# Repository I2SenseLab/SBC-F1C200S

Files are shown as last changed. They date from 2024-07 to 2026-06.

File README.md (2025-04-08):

Remember to Initialize Submodules

```
git submodule update --init
```

To Grab the device defconfig

```
BR2_EXTERNAL=../simple_sbc make f1c200s_simple_sbc_defconfig
```

To make modifications to the config run

```
make menuconfig or xconfig (recommended)
```

To make the actual bin file run

```
make clean
make
```

To make on WSL with a slightly wonky path try

```
PATH=$(grep -v '[[:space:]]'<<<"${PATH//:/$'\n'}"|paste -sd:) make
```

```
To save changes to the defconfig
```

make savedefconfig

```

## JLCPCB Fabrication Note 

The usb differential traces have been routed according to this using their online calculator. Other processes will need these trace widths to be adjusted.

| Impedance (Ω) | Type                     | Signal Layer | Top Ref | Bottom Ref | Trace Width (mm) | Trace Spacing (mm) | Impedance Trace to Copper (mm) |
|--------------|-------------------------|--------------|---------|------------|------------------|------------------|----------------------------|
| 90           | Coplanar Differential Pair | L1           | /       | L2         | 0.1974           | 0.1300           | 0.1900                     |
| 90           | Coplanar Differential Pair | L2           | L1      | L3         | 0.1511           | 0.1300           | 0.1900                     |
| 90           | Coplanar Differential Pair | L3           | L2      | L4         | 0.1511           | 0.1300           | 0.1900                     |
| 90           | Coplanar Differential Pair | L4           | L3      | /          | 0.1974           | 0.1300           | 0.1900                     |

## To write img file into sd card we use in linux

```

sudo dd if=sdcard.img of=/dev/* bs=1M status=progress
sync

```

Note 'of=/dev/*' make sure you choose the correct dev device for the appropriate sd card

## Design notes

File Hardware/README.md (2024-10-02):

# Design Notes - Erata 

Initial Board Ordered 9th July 2024 - $148.59
This was for 5 boards assembled. There were a few minor issues with the initial board which have been both corrected and improved upon.

- The board moves the SD Card to the correct interface. This should allow full size SD cards to be run. I would assume a 32GB limit however.
- 16MB of Nand flash has been added to the design to act as the boot rom 
- A RP2040 and associated circuitry has been added to facilitate easy communication through the F1C200S UART interface without requiring USB Gadget to be fully functional initially.

# Note
- Manually Verified and Adjusted the uploaded Bill of Materials.
- At time of writing October 2nd, waiting on JLCPCB parts order to be fully fulfilled before placing PCB order.

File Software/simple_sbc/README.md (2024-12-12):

## Usage
The board has an unpopulated header for the SPI0 port which can be used to write to the flash chip directly. The F1C100 chip also includes a USB stack and SPI Flash driver in the internal bootloader in "FEL" mode, which can be used to write to the first 16MB of the chip.
* To force the device in to FEL mode, first bridge the CS pin with 3v3 to pull the line high and make the F1c100 footloader think there is no boot device.
* Plug the board in to a PC via USB. The LCD should light up white, and the device should enumerate as a USB device.
* Remove the bridge from chip select (CS) pin.
* Follow the instructions to get **sunxi-tools** for your OS [here](https://linux-sunxi.org/FEL).
* Build the Buildroot external tree:
```
BR2_EXTERNAL=../simple_sbc make f1c200s_simple_sbc_defconfig
```
* Use **sunxi-fel** to write the *flash.bin* file to the flash drive:
```
./sunxi-fel -p spiflash-write 0 flash.bin
```
* Reboot the device by either bridging the *reset* jumper, or clycling power.

## Benchmark Results 

# dhrystone

Dhrystone Benchmark, Version 2.1 (Language: C)

Program compiled without 'register' attribute

Please give the number of runs through the benchmark: 1000000000

Execution starts, 1000000000 runs through Dhrystone
Execution ends

Final values of the variables used in the benchmark:

Int_Glob:            5
        should be:   5
Bool_Glob:           1
        should be:   1
Ch_1_Glob:           A
        should be:   A
Ch_2_Glob:           B
        should be:   B
Arr_1_Glob[8]:       7
        should be:   7
Arr_2_Glob[8][7]:    1000000010
        should be:   Number_Of_Runs + 10
Ptr_Glob->
  Ptr_Comp:          94608
        should be:   (implementation-dependent)
  Discr:             0
        should be:   0
  Enum_Comp:         2
        should be:   2
  Int_Comp:          17
        should be:   17
  Str_Comp:          DHRYSTONE PROGRAM, SOME STRING
        should be:   DHRYSTONE PROGRAM, SOME STRING
Next_Ptr_Glob->
  Ptr_Comp:          94608
        should be:   (implementation-dependent), same as above
  Discr:             0
        should be:   0
  Enum_Comp:         1
        should be:   1
  Int_Comp:          18
        should be:   18
  Str_Comp:          DHRYSTONE PROGRAM, SOME STRING
        should be:   DHRYSTONE PROGRAM, SOME STRING
Int_1_Loc:           5
        should be:   5
Int_2_Loc:           13
        should be:   13
Int_3_Loc:           7
        should be:   7
Enum_Loc:            1
        should be:   1
Str_1_Loc:           DHRYSTONE PROGRAM, 1'ST STRING
        should be:   DHRYSTONE PROGRAM, 1'ST STRING
Str_2_Loc:           DHRYSTONE PROGRAM, 2'ND STRING
        should be:   DHRYSTONE PROGRAM, 2'ND STRING

Microseconds for one run through Dhrystone:    1.8
Dhrystones per Second:                      565163.3

## Acknowledgments
This project is based heavily on the work of others; I would like to acknowledge these project in particular:
* https://github.com/thirtythreeforty/businesscard-linux/tree/master
* https://github.com/florpor/licheepi-nano/tree/master
* [F1C100 Datasheet](https://whycan.com/files/members/3/F1C100s_Datasheet_V1_0.pdf)
* [Lichee-Pi Nano](https://wiki.sipeed.com/hardware/en/lichee/Nano/Nano.html)

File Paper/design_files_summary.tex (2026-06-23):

\begin{tabu} to \linewidth {|X|X|X[1.5,1]|X[1.5,1]|}
\hline
\textbf{Design filename} & \textbf{File type} & \textbf{Open source license} & \textbf{Location of the file} \\hline

SimpleSBC.dip & DipTrace schematic and PCB design files & Apache-2.0 & Repository associated with this article \\hline

SimpleSBC_gerber.zip & Manufacturing files (Gerber, drill, fabrication outputs) & Apache-2.0 & Repository associated with this article \\hline

sbcBOM.csv & Bill of materials & Apache-2.0 & Repository associated with this article \\hline

sbcPNP.csv & Pick-and-place assembly file & Apache-2.0 & Repository associated with this article \\hline

SimpleSBC_EnclosureTop.stl, SimpleSBC_EnclosureBottom.stl & Mechanical enclosure CAD files & Apache-2.0 & Repository associated with this article \\hline

f1c200s_simple_sbc.dts, f1c200s_simple_sbc.dtsi & Linux device tree source files & Apache-2.0 & Repository associated with this article \\hline

f1c200s_simple_sbc_defconfig & Buildroot configuration files & Apache-2.0 & Repository associated with this article \\hline

pico-uart-bridge & RP2040 USB-to-UART firmware source code & Apache-2.0 & Repository associated with this article \\hline

0001-st7789v-support-dc-gpio-8bit-spi.patch & Linux kernel patch enabling LCD support & Apache-2.0 & Repository associated with this article \\hline

\end{tabu}

\vskip 0.3cm

\textbf{SimpleSBC.dip} \
DipTrace project containing the complete schematic and PCB layout of the single-board computer. This file may be modified to adapt the design to alternative research applications or form factors.

\textbf{SimpleSBC_gerber.zip} \
Manufacturing-ready fabrication files used for PCB production. These files can be directly submitted to PCB fabrication services.

\textbf{sbcBOM.csv} \
Bill of materials listing all components required to assemble the hardware platform, including manufacturer part numbers and quantities.

\textbf{sbcPNP.csv} \
Pick-and-place file used for automated assembly of the PCB. This file enables low-cost assembly through commercial PCB assembly services.

\textbf{SimpleSBC_EnclosureTop.stl, SimpleSBC_EnclosureBottom.stl} \
3D-printable enclosure files providing mechanical protection for the assembled board while maintaining access to connectors and interfaces.

\textbf{f1c200s_simple_sbc.dts, f1c200s_simple_sbc.dtsi} \
Linux device tree descriptions defining the hardware configuration of the board, including peripheral mappings and display interfaces.

\textbf{f1c200s_simple_sbc_defconfig} \
Buildroot configuration used to generate a reproducible embedded Linux image for the platform.

\textbf{pico-uart-bridge} \
Firmware source code for the RP2040-based USB-to-UART bridge used during software development and debugging of the board.

\textbf{0001-st7789v-support-dc-gpio-8bit-spi.patch} \
Linux kernel patch providing support for the integrated ST7789V display interface used by the hardware platform.

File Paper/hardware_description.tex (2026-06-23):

\section{Hardware description}

The Simple SBC is a compact Linux-capable single-board computer designed as a 
customizable foundation for research and educational projects. Unlike 
commercial SBCs, which are typically designed as general-purpose computing 
platforms, the Simple SBC is intended to serve as a starting point for 
application-specific hardware development. The design integrates the minimum 
set of components required to support a Linux operating system while reserving 
a significant portion of the PCB area for application-specific circuitry.

The board combines a Linux-capable microprocessor, memory, power management circuitry, 
storage interfaces, and external communication interfaces onto a single PCB. 
By integrating these functions directly into the design, researchers can avoid the need 
for separate carrier boards or expansion modules commonly required when adapting commercial 
SBCs to specialized applications. The resulting system reduces overall component count and 
provides greater flexibility for hardware customization.

A key feature of the design is the inclusion of a large prototyping and expansion region 
intended for daughter-board integration. This area allows application-specific circuitry 
to be incorporated directly into the system while maintaining access to Linux-based software 
infrastructure. As a result, custom sensors, control electronics, communication interfaces, 
or experimental hardware can be developed as part of a unified platform rather than as 
external peripherals connected through standard expansion headers.

The design is fully open source, with schematic and PCB design files provided to enable 
modification and reuse. Researchers may adapt the board to alternative form factors, 
remove unused peripherals, or integrate additional functionality directly into the base design. 
This flexibility allows the platform to evolve alongside project requirements without requiring 
a complete redesign of the Linux subsystem.

Compared to commercial SBC platforms, the Simple SBC prioritizes customization and integration 
over processing performance. While it does not seek to replace high-performance platforms 
such as the Raspberry Pi, it provides a practical solution for applications where a Linux 
operating system is required but where the size, cost, or fixed architecture of a commercial 
board may be limiting factors.

The hardware may be useful to researchers in the following ways:

\begin{itemize}
\item Provides a Linux-capable computing platform that can be directly integrated into 
custom research hardware without requiring a separate commercial SBC.

\item Includes a dedicated daughter-board region that simplifies the integration of sensors, 
actuators, communication interfaces, and other application-specific electronics.

\item Enables modification of the PCB layout and schematic files to support specialized form factors, 
environmental constraints, or experimental requirements.

\item Serves as a reference design for researchers interested in developing custom 
embedded Linux systems without designing the complete hardware and software stack from scratch.

\item Supports educational activities involving embedded Linux, hardware design, 
and system integration by providing a fully open-source example platform.

\end{itemize}

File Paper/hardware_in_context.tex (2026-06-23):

\section{Hardware in context}

Single-board computers (SBCs) have become an important platform for research, education, 
and rapid prototyping. 
Platforms such as the Raspberry Pi provide a low-cost and accessible method for deploying Linux-based 
applications, acquiring data, and interfacing with external hardware. 
As a result, Raspberry Pi systems are frequently adopted in laboratory environments, 
educational settings, and early-stage research prototypes.

Despite their popularity, commercial SBCs are not ideal for every application. 
Research projects often require only a subset of the functionality provided by a general-purpose 
computer, while simultaneously requiring specialized interfaces, custom form factors, 
reduced power consumption, or lower deployment costs. 
Integrating these requirements around an off-the-shelf SBC frequently necessitates the design of 
additional carrier boards, interface adapters, or custom expansion hardware, 
increasing both system complexity and overall cost.

The Simple SBC presented in this work provides an alternative design path for 
applications that require a Linux-capable embedded platform but do not require 
the full performance or ecosystem of a Raspberry Pi. 
Rather than serving as a direct replacement, 
the design demonstrates how a low-cost Linux computer can be integrated into a 
custom hardware platform using components that are readily available through 
commercial PCB fabrication and assembly services. 
The board includes the processing, memory, power regulation, storage, 
and expansion interfaces necessary to operate a Linux-based system while 
maintaining a compact and customizable architecture.

The design was inspired by prior demonstrations of minimal Linux-capable hardware, 
including the Linux Business Card project by \citeauthor{hilliard_business_card_linux_2019} 
\cite{hilliard_business_card_linux_2019} and the embedded Linux design guidance presented 
by Carlson \cite{carlson_embedded_linux}. These projects demonstrated that practical 
Linux systems can be constructed using a relatively small number of components and 
provided valuable insight into hardware design, boot processes, and software integration. 
Building upon these concepts, the Simple SBC extends the idea into a reusable research 
platform intended for customization, experimentation, and integration into larger embedded systems.

The resulting platform occupies a middle ground between highly integrated commercial SBCs 
and fully custom embedded Linux designs. It provides researchers, educators, and developers 
with an open-source reference design that can be fabricated, modified, and integrated 
into application-specific hardware while retaining the flexibility and software 
ecosystem of a Linux-based system.

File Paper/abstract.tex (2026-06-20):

\textbf{Abstract}\\ 
The Raspberry Pi Computer is an incredible tool for numerous research applications. 
However, despite wide usage it is not ideal for all research applications. 
Using a Raspberry Pi can increase costs, overall prototype size, and decrease flexibility. 
For this reason we have designed a simple single board computer based around a low-cost MPU available for cheap assembly. 
The design pairs the F1C200S Allwinner MPU with the RP2040 MCU. 
The operating system can be loaded either onto the attached microSD slot or loadded directly onto the on-board flash.
The design is open source and can be used either as is with a large area dedicated to support a daughter board for specialized 
research applciations, or the design can be customized directly to integrate within another project. 
This makes the system ideal for long term data-logging in environments where using a Raspberry Pi would represent a significant unneeded cost. 

%Insert Keywords
\textbf{Keywords}\\ Single Board Computer, Embedded Linux, Microcontrollers

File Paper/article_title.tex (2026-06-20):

\textbf{Article title}\\ 
Simple Single Board Computer for Low-Budget Research Applications

%Insert Authors
\textbf{Authors}\\ 
Devin Atkin *, Santiago Fuentes, Orly Yadid-Pecht

%Insert Affiliations
\textbf{Affiliations}\\ 
University of Calgary

%Insert Contact Email
%Include institutional email address of the corresponding author
\textbf{Corresponding author’s email address and Twitter handle}\\ 
dmatkin@ucalgary.ca, X: @devinatkin

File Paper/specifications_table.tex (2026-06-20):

\textbf{Specifications table}\\
\textit{Please replace the italicizied instructions in the right column of the table with the relevant information about your hardware.}
\vskip 0.2cm
\tabulinesep=1ex
\begin{tabu} to \linewidth {|X|X[3,l]|}
\hline  \textbf{Hardware name} & Simple Single Board Computer
    \\
    \hline \textbf{Subject area} & Educational tools and open source alternatives to existing infrastructure
    \\
    \hline \textbf{Hardware type} & Electrical engineering and computer science
    \end{itemize}
    \\ 
    \hline \textbf{Closest commercial analog} & Raspberry Pi Computer/ Raspberry Pi Compute Module
    \\
    \hline \textbf{Open source license} & CERN-OHL-P
    \\
    \hline \textbf{Cost of hardware} & \$80
    \\
    \hline \textbf{Source file repository} & https://doi.org/10.17632/wpywd4tdy8.1
    % \\
    % \hline \textbf{OSHWA certification UID} \vskip 0.1cm {\it (OPTIONAL)} &
    \\\hline
\end{tabu}

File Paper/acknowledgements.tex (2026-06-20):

\textbf{Acknowledgements}\\
\noindent

The authors would like to thank the developers and maintainers of the open-source software projects that made this work possible. 
In particular, 
the Buildroot community is acknowledged for providing the embedded Linux build system used in the development and validation of the presented single-board computer platform.

Large language model (LLM) tools were used to assist with language refinement, editing, 
and preparation of portions of the manuscript. 
All technical content, design decisions, analysis, and conclusions were reviewed and verified by the authors, 
who take full responsibility for the contents of this publication.

Funding: This research did not receive any specific grant from funding agencies in the public, commercial, 
or not-for-profit sectors.

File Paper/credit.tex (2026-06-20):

\textbf{CRediT author statement}\\
\noindent

Devin Atkin: Conceptualization, Methodology, Hardware design, Validation, Investigation, Resources, Visualization, Writing – Original Draft, Writing – Review & Editing, Project administration.

Santiago Fuentes: Software, Validation, Investigation, Writing – Original Draft, Writing – Review & Editing.

Orly Yadid-Pecht: Conceptualization, Methodology, Supervision, Resources, Writing – Review & Editing, Funding acquisition.

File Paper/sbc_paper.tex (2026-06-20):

% GENERAL INFORMATION: HardwareX is an open access journal established to promote free and open source designing, building and customizing of scientific infrastructure (hardware). For more details on best practices for sharing open hardware see http://www.oshwa.org/sharing-best-practices/

\documentclass[11pt, letterpaper]{article}
\usepackage[utf8]{inputenc}
\usepackage[margin=1.5cm]{geometry}
\usepackage{titlesec}
\usepackage{tabu}
\usepackage{enumitem}
\usepackage{amssymb}
\usepackage{xcolor}
\newlist{selectlist}{itemize}{2}
\setlist[selectlist]{label=$\square$,leftmargin=*,noitemsep,topsep=0pt}

\usepackage{lmodern}

\usepackage[
backend=biber,
style=ieee
]{biblatex}
\addbibresource{references.bib}

\usepackage{hyperref}
\hypersetup{
    colorlinks=true,
    linkcolor=blue,
    filecolor=magenta,      
    urlcolor=blue,
}
 
\urlstyle{same}

% Set up the section label formatting
\titleformat{\section}[block]{\hspace{1em}\bfseries}{\thesection.}{0.5em}{} 
\titleformat{\subsection}[block]{\hspace{1em}}{\thesubsection}{0.5em}{}

\begin{document}
\begin{flushleft}

\setlength{\parindent}{0pt}
\setlength{\parskip}{10pt}

\input{article_title}

\input{abstract}

\newpage

\input{specifications_table}

\end{flushleft}

% create the main body of the paper
\newpage

\input{hardware_in_context}

\input{hardware_description}

\input{design_files_summary}

\input{bill_of_materials}

\input{build_instructions}

\input{operation_instructions}

\input{validation_and_characterization}

\noindent

\noindent

\input{credit}

\noindent

\input{acknowledgements}

\noindent

\printbibliography

\end{document}

%> Author manuscript checklist
%> ●	HardwareX is a journal dedicated to the exhaustive and fully open source communication of advances in scientific infrastructure. Upon submission the author declares that all information necessary to reproduce the subject of the submission (e.g. bill of materials, build instructions, calibration procedures, source files, code, and safety considerations) is communicated in full and is accessible for use under an open source license. 
%> ●	Is the subject of the submission under an open source license? Are design files in the preferred format for making modifications? As defined by the Open Source Hardware definition. 
%> ●	Can the hardware be reproduced with the details provided in the submission?
%> ●	Are all relevant design files available on Mendeley Data, the Open Science Framework, or Zenodo repositories, described in the Summary of Design Files document, and clearly documented? (e.g. descriptive file names, commented code, labeled images, etc.) 
%>      ○	If in the Open Science Framework, the repository has be registered? Instructions
%>      ○	If in Zenodo, the repository is open access and is published? Instructions
%>      ○	If in Mendeley Data, the repository is published or the sharable link was included in the additional information of the Editorial Submission interface? Instructions
%> ●	Are visual instructions used when necessary?
%> ●	Is the utility of the hardware to the scientific community? Has a specific scientific application been demonstrated using the hardware?
%> ●	Is the performance of the hardware adequately demonstrated and characterized?
%> ●	Are all potential safety concerns addressed?
%> ●	For more information on the article template consult the Guide to Authors.}

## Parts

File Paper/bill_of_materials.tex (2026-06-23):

\section*{\textit{Bill of materials}}

The complete bill of materials is provided in the project repository as \texttt{Hardware/sbcBOM.csv}. The reference designators in the bill of materials match the designators used in the schematic and PCB layout files. For readability, repeated passive components with the same package and supplier part number are grouped in the summary table below. The full editable CSV file should be used for ordering, assembly, and detailed component-level verification.

\section{Bill of materials summary}

\vskip 0.2cm
\tabulinesep=1ex
\noindent
\begin{tabu} to \linewidth {|X[1.1,1]|X|X[0.6,1]|X[0.8,1]|X|X|X[1.1,1]|}
\hline
\textbf{Designator} & \textbf{Component} & \textbf{Number} & \textbf{Cost per unit - currency} & \textbf{Total cost - currency} & \textbf{Source of materials} & \textbf{Material type} \\hline

C1--C47 & Ceramic capacitors, assorted values and footprints & 50 & See complete BOM & See complete BOM & JLCPCB/LCSC & Ceramic \\hline

D1--D8 & Indicator LEDs, 0603 package & 8 & See complete BOM & See complete BOM & JLCPCB/LCSC & Semiconductor \\hline

J1, J5, J7, J9_1, J9_2 & Connectors including audio jack, pin headers, and USB-C connectors & 5 & See complete BOM & See complete BOM & JLCPCB/LCSC & Composite \\hline

L2 & Surface-mount inductor & 1 & See complete BOM & See complete BOM & JLCPCB/LCSC & Metal \\hline

Q1_1--Q4_2 & Power MOSFETs in PowerFLAT package & 8 & See complete BOM & See complete BOM & JLCPCB/LCSC & Semiconductor \\hline

R1--R47 & Surface-mount resistors, assorted values and footprints & 52 & See complete BOM & See complete BOM & JLCPCB/LCSC & Ceramic \\hline

S1--S4 & Surface-mount tactile switches & 4 & See complete BOM & See complete BOM & JLCPCB/LCSC & Composite \\hline

U1 & microSD card connector & 1 & See complete BOM & See complete BOM & JLCPCB/LCSC & Composite \\hline

U2, U7 & W25Q128 SPI flash memory & 2 & See complete BOM & See complete BOM & JLCPCB/LCSC & Semiconductor \\hline

U3 & AZ1117 linear voltage regulator & 1 & See complete BOM & See complete BOM & JLCPCB/LCSC & Semiconductor \\hline

U6 & RP2040 microcontroller & 1 & See complete BOM & See complete BOM & JLCPCB/LCSC & Semiconductor \\hline

U8 & Allwinner F1C200s system-on-chip & 1 & See complete BOM & See complete BOM & JLCPCB/LCSC & Semiconductor \\hline

U10 & ADP323 power-management regulator & 1 & See complete BOM & See complete BOM & JLCPCB/LCSC & Semiconductor \\hline

U11 & Power-management or support IC & 1 & See complete BOM & See complete BOM & JLCPCB/LCSC & Semiconductor \\hline

U14_1, U14_2 & STUSB1600A USB Type-C controller & 2 & See complete BOM & See complete BOM & JLCPCB/LCSC & Semiconductor \\hline

Y1 & 12 MHz crystal oscillator / resonator & 1 & See complete BOM & See complete BOM & JLCPCB/LCSC & Inorganic \\hline

Y2 & 24 MHz crystal oscillator / resonator & 1 & See complete BOM & See complete BOM & JLCPCB/LCSC & Inorganic \\hline

PCB & Custom printed circuit board & 1 & See fabrication quote & See fabrication quote & JLCPCB or equivalent PCB manufacturer & Composite \\hline

Enclosure & 3D-printed top and bottom enclosure pieces & 2 & See fabrication quote & See fabrication quote & 3D printing service or local fabrication & Polymer \\hline

\end{tabu}\

\vskip 0.2cm

\noindent
The hardware is primarily assembled from commercially available surface-mount components selected for compatibility with low-cost PCB fabrication and assembly services. The complete bill of materials includes the manufacturer or supplier part numbers, datasheet links where available, footprints, reference designators, and JLCPCB/LCSC part numbers. Costs are intentionally reported through the editable BOM and fabrication quotations because component pricing and availability vary over time, particularly for semiconductor devices and PCB assembly services.

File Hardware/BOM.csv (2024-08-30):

Comment | RefDes | Pattern | JLCPCB
1 CAP_0402_7pF Murata Electronics 7pF | C1, C2 | CAP_0402_N | C307438
2 CAP_0805_M 8pf | C3, C4 | CAP_0805_M
0805 1u | C7 | CAP_0805_M
3 CAP_0603_N 0.1u | C5 | CAP_0603_N | C694145
4 CAP_0603_M 1u | C6, C8, C9 | CAP_0603_M | C15849
5 YellowLED Yellow LED | D1, D2, D3, D4, D5, D6, D7, D8 | DIO_0603_L | C72038
6 PJ-320(OS) HOOYA | J1 | PJ-320 | C2939180
7 TYPE-C-31-M-12 Korean Hroparts Elec | J2, J3 | C165948 | C165948
8 PPTC041LFBN-RC Sullins | J4, J8 | RHDRV4W80P254_4X1_1066X250H875_AP1
9 A2541HWV-2P CJT(Changjiang Connectors) | J5 | RHDRV2W80P254_2X1_558X250H875_AP1 | C225499
10 PPTC061LFBN-RC Sullins | J6, J7 | RHDRV6W80P254_6X1_1574X250H875_AP1
11 RES_0402_N 5K1 | R1, R2, R3, R4, R15, R25, R26, R27, R28 | RES_0402_N | C400635
12 RES_0805_M 300 | R5, R6, R7, R8, R9, R10, R11, R12 | RES_0805_M | C352224
13 RES_0402_27.4 27.4 | R13, R14 | RES_0402_M | C31439
14 RES_0805_N 56k | R16, R17, R18, R19, R20, R21, R22, R31, R32, R33, R34, R35, R36 | RES_0805_N | C2828780
15 RES_0402_1K 1K | R23, R24 | RES_0402_N | C11702
16 RES_0603_M 0 | R29, R30 | RES_0603_M | C21189
17 TS-1088-AR02016 | S1, S2, S3, S4 | C720477 | C720477
18 GT-TF003-H0185-01 G-Switch | U1 | GT-TF003-H0185-01 | C5155563
19 W25Q128JVSIQ Winbond Elec 128Mbit | U2, U7 | SOIC8P127_528X790X216L65X41N | C97521
20 MAX40200AUK+T Analog Devices PD Switch | U3, U4 | SOT23-5P65_210X100L36X22M | C2649430
21 2x20 Header | U5 | HEADER40 | C19192096
22 RP2040 Raspberry Pi | U6 | RP2040 | C2040
23 F1C200S | U8 | QFN89P40_1000X1000X90L40X20T674M | C2879851
24 TLV73311PDQNR Texas Instruments 1.11V | U9 | X2SON | C2863780
25 ADP323 Analog Devices | U10 | QFN17P50_300X300X80L40X24T160N | C143893
26 RPI_HEADER | U11 | HEADER40 | C19192096
27 7M12000039 TXC Corp 12Mhz | Y1 | 7M12000039 | C90900
28 X322524MMB4SI Yangxing Tech 24MHZ 7PF | Y2 | X322524MMB4SI | C70583

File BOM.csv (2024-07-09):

Comment | RefDes | Pattern | JLCPCB
1u | C1, C2, C3 | CAP_0603_M | C15849
0.1u | C4 | CAP_0603_N | C694145
8pf | C5, C7 | CAP_0805_M | C296108
1u | C6 | CAP_0805_M | C377011
https://datasheet.lcsc.com/lcsc/1810101813_Everlight-Elec-19-213-Y2C-CQ2R2L-3T-CY_C72038.pdf | D1, D2 | DIO_0603_L | C72038
http://datasheets.diptrace.com/con_headers/xPxCxxxLFBN-RC_10492-E.pdf | J1 | RHDRV22W80P254_22X1_5638X250H875_AP1
http://datasheets.diptrace.com/con_headers/xPxCxxxLFBN-RC_10492-E.pdf | J2, J6, J9 | RHDRV4W80P254_4X1_1066X250H875_AP1
https://datasheet.lcsc.com/lcsc/1811131825_Korean-Hroparts-Elec-TYPE-C-31-M-12_C165948.pdf | J3 | C165948 | C165948
http://datasheets.diptrace.com/con_headers/xPxCxxxLFBN-RC_10492-E.pdf | J4, J8, J10, J11 | RHDRV6W80P254_6X1_1574X250H875_AP1
https://jlcpcb.com/partdetail/Hooya-PJ_320_OS/C2939180 | J5 | PJ-320 | C2939180
http://datasheets.diptrace.com/con_headers/xPxCxxxLFBN-RC_10492-E.pdf | J7 | RHDRV13W80P254_13X1_3352X250H875_AP1
0 | R1, R2, R5 | RES_0603_M
5k1 | R3, R4 | RES_0402_N
22k | R8, R15, R16 | RES_0402_N
300 | R6, R7 | RES_0805_M
56k | R9 | RES_0805_N
46k | R10 | RES_0805_N
40k | R11 | RES_0805_N
10k | R12, R13, R14 | RES_0805_N
 | S1 | C720477 | C720477
https://jlcpcb.com/partdetail/gswitch-GT_TF003_H018501/C5155563 | U1 | GT-TF003-H0185-01 | C5155563
F1C200S | U2 | QFN89P40_1000X1000X90L40X20T674M
https://jlcpcb.com/partdetail/AnalogDevices-ADP323ACPZR7/C143893 | U3 | QFN17P50_300X300X80L40X24T160N | C143893
https://jlcpcb.com/partdetail/TexasInstruments-TLV73311PDQNR/C2863780 | U4 | X2SON | C2863780
file:///C:/Users/devin/Downloads/X322524MMB4SI.pdf | Y1 | X322524MMB4SI | C70583

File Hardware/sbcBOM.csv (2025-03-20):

# | Datasheet | RefDes | Pattern | JLCPCB
1 | https://datasheet.lcsc.com/lcsc/1810231041_Samsung-Electro-Mechanics-CL05C070DB5NNNC_C307438.pdf | C1 | CAP_0402_N | C1577
2 | https://datasheet.lcsc.com/lcsc/1810231041_Samsung-Electro-Mechanics-CL05C070DB5NNNC_C307438.pdf | C2 | CAP_0402_N | C1577
3 | http://datasheets.diptrace.com/yageo/CC0603JRNPO9BN560_and_series.pdf | C3 | CAPP_0402_M | C161160
4 | http://datasheets.diptrace.com/yageo/CC0603JRNPO9BN560_and_series.pdf | C4 | CAPP_0402_M | C161160
5 | http://datasheets.diptrace.com/yageo/CC0603JRNPO9BN560_and_series.pdf | C5 | CAP_0402_M | C432917
6 |  | C6 | CAP_0603_M | C15849
7 |  | C7 | CAP_0603_M | C15849
8 |  | C8 | CAP_0603_M | C15849
9 |  | C9 | CAP_0603_M | C15849
10 | http://datasheets.diptrace.com/yageo/CC0603JRNPO9BN560_and_series.pdf | C13 | CAP_0402_M | C432917
11 | http://datasheets.diptrace.com/yageo/CC0603JRNPO9BN560_and_series.pdf | C14 | CAP_0402_M | C432917
12 | http://datasheets.diptrace.com/yageo/CC0603JRNPO9BN560_and_series.pdf | C15 | CAP_0402_M | C432917
13 | http://datasheets.diptrace.com/yageo/CC0603JRNPO9BN560_and_series.pdf | C16 | CAP_0402_M | C432917
14 | http://datasheets.diptrace.com/yageo/CC0603JRNPO9BN560_and_series.pdf | C17 | CAP_0402_M | C432917
15 | http://datasheets.diptrace.com/yageo/CC0603JRNPO9BN560_and_series.pdf | C18 | CAP_0402_M | C432917
16 | http://datasheets.diptrace.com/yageo/CC0603JRNPO9BN560_and_series.pdf | C19 | CAP_0402_M | C432917
17 | http://datasheets.diptrace.com/yageo/CC0603JRNPO9BN560_and_series.pdf | C20 | CAP_0402_M | C432917
18 | http://datasheets.diptrace.com/yageo/CC0603JRNPO9BN560_and_series.pdf | C21 | CAP_0402_M | C432917
19 | http://datasheets.diptrace.com/yageo/CC0603JRNPO9BN560_and_series.pdf | C22 | CAP_0402_M | C432917
20 | http://datasheets.diptrace.com/yageo/CC0603JRNPO9BN560_and_series.pdf | C23 | CAP_0402_M | C432917
21 | http://datasheets.diptrace.com/yageo/CC0603JRNPO9BN560_and_series.pdf | C24 | CAP_0402_M | C432917
22 | http://datasheets.diptrace.com/yageo/CC0603JRNPO9BN560_and_series.pdf | C25 | CAP_0402_M | C432917
23 | http://datasheets.diptrace.com/yageo/CC0603JRNPO9BN560_and_series.pdf | C26 | CAP_0402_M | C432917
24 | http://datasheets.diptrace.com/yageo/CC0603JRNPO9BN560_and_series.pdf | C27 | CAP_0402_M | C432917
25 | http://datasheets.diptrace.com/yageo/CC0603JRNPO9BN560_and_series.pdf | C28 | CAP_0402_M | C432917
26 | http://datasheets.diptrace.com/yageo/CC0603JRNPO9BN560_and_series.pdf | C29 | CAP_0402_M | C432917
27 | http://datasheets.diptrace.com/yageo/CC0603JRNPO9BN560_and_series.pdf | C30 | CAP_0402_M | C432917
28 | http://datasheets.diptrace.com/yageo/CC0603JRNPO9BN560_and_series.pdf | C31 | CAP_0402_M | C432917
29 | http://datasheets.diptrace.com/yageo/CC0603JRNPO9BN560_and_series.pdf | C32 | CAP_0402_M | C432917
30 | http://datasheets.diptrace.com/yageo/CC0603JRNPO9BN560_and_series.pdf | C33 | CAP_0402_M | C432917
31 |  | C34 | CAP_0603_M | C15849
32 |  | C35 | CAP_1206_M | C1859
33 |  | C36 | CAPP_0805_M | C1713
34 |  | C37 | CAP_0805_M | C1746
35 |  | C38 | CAP_0805_M | C1711
36 |  | C39 | CAP_0805_M | C1711
37 |  | C40 | CAP_0805_M | C1745
38 | http://datasheets.diptrace.com/yageo/CC0603JRNPO9BN560_and_series.pdf | C41 | CAP_0402_M | C432917
39 | http://datasheets.diptrace.com/yageo/CC0603JRNPO9BN560_and_series.pdf | C42 | CAP_0402_M | C432917
40 | http://datasheets.diptrace.com/yageo/CC0603JRNPO9BN560_and_series.pdf | C43 | CAP_0402_M | C432917
41 | http://datasheets.diptrace.com/yageo/CC0603JRNPO9BN560_and_series.pdf | C44 | CAP_0402_M | C432917
42 |  | C45 | CAP_0603_M | C15849
43 |  | C46 | CAP_0603_M | C15849
44 |  | C47 | CAP_0603_M | C15849
45 |  | C10_1 | CAP_0603_M | C15849
46 |  | C10_2 | CAP_0603_M | C15849
47 |  | C11_1 | CAP_0603_M | C15849
48 |  | C11_2 | CAP_0603_M | C15849
49 |  | C12_1 | CAP_0603_M | C15849
50 |  | C12_2 | CAP_0603_M | C15849
51 | https://datasheet.lcsc.com/lcsc/1810101813_Everlight-Elec-19-213-Y2C-CQ2R2L-3T-CY_C72038.pdf | D1 | DIO_0603_L | C72038
52 | https://datasheet.lcsc.com/lcsc/1810101813_Everlight-Elec-19-213-Y2C-CQ2R2L-3T-CY_C72038.pdf | D2 | DIO_0603_L | C72038
53 | https://datasheet.lcsc.com/lcsc/1810101813_Everlight-Elec-19-213-Y2C-CQ2R2L-3T-CY_C72038.pdf | D3 | DIO_0603_L | C72038
54 | https://datasheet.lcsc.com/lcsc/1810101813_Everlight-Elec-19-213-Y2C-CQ2R2L-3T-CY_C72038.pdf | D4 | DIO_0603_L | C72038
55 | https://datasheet.lcsc.com/lcsc/1810101813_Everlight-Elec-19-213-Y2C-CQ2R2L-3T-CY_C72038.pdf | D5 | DIO_0603_L | C72038
56 | https://datasheet.lcsc.com/lcsc/1810101813_Everlight-Elec-19-213-Y2C-CQ2R2L-3T-CY_C72038.pdf | D6 | DIO_0603_L | C72038
57 | https://datasheet.lcsc.com/lcsc/1810101813_Everlight-Elec-19-213-Y2C-CQ2R2L-3T-CY_C72038.pdf | D7 | DIO_0603_L | C72038
58 | https://datasheet.lcsc.com/lcsc/1810101813_Everlight-Elec-19-213-Y2C-CQ2R2L-3T-CY_C72038.pdf | D8 | DIO_0603_L | C72038
59 | https://jlcpcb.com/partdetail/Hooya-PJ_320_OS/C2939180 | J1 | PJ-320 | C2939180
60 | https://datasheet.lcsc.com/lcsc/2010160505_CJT-Changjiang-Connectors-A2541HWV-8P_C225505.pdf | J5 | RHDRV2W80P254_2X1_558X250H875_AP1 | C225499
61 | http://datasheets.diptrace.com/con_headers/xPxCxxxLFBN-RC_10492-E.pdf | J7 | RHDRV6W80P254_6X1_1574X250H875_AP1 | C40877
62 | https://datasheet.lcsc.com/lcsc/1811131825_Korean-Hroparts-Elec-TYPE-C-31-M-12_C165948.pdf | J9_1 | C165948 | C165948
63 | https://datasheet.lcsc.com/lcsc/1811131825_Korean-Hroparts-Elec-TYPE-C-31-M-12_C165948.pdf | J9_2 | C165948 | C165948
64 |  | L2 | SM5845 | C14258
65 | https://jlcpcb.com/api/file/downloadByFileSystemAccessId/8589838170629582848 | Q1_1 | Powerflat 3x3 | C2969828
66 | https://jlcpcb.com/api/file/downloadByFileSystemAccessId/8589838170629582848 | Q1_2 | Powerflat 3x3 | C2969828
67 | https://jlcpcb.com/api/file/downloadByFileSystemAccessId/8589838170629582848 | Q2_1 | Powerflat 3x3 | C2969828
68 | https://jlcpcb.com/api/file/downloadByFileSystemAccessId/8589838170629582848 | Q2_2 | Powerflat 3x3 | C2969828
69 | https://jlcpcb.com/api/file/downloadByFileSystemAccessId/8589838170629582848 | Q3_1 | Powerflat 3x3 | C2969828
70 | https://jlcpcb.com/api/file/downloadByFileSystemAccessId/8589838170629582848 | Q3_2 | Powerflat 3x3 | C2969828
71 | https://jlcpcb.com/api/file/downloadByFileSystemAccessId/8589838170629582848 | Q4_1 | Powerflat 3x3 | C2969828
72 | https://jlcpcb.com/api/file/downloadByFileSystemAccessId/8589838170629582848 | Q4_2 | Powerflat 3x3 | C2969828
73 |  | R1 | RES_0805_N | C17444
74 |  | R2 | RES_0805_N | C104362
75 |  | R3 | RES_0603_M | C21189
76 |  | R5 | RES_0805_M | C352224
77 |  | R6 | RES_0805_M | C352224
78 |  | R7 | RES_0805_M | C352224
79 |  | R8 | RES_0805_M | C352224
80 |  | R9 | RES_0805_M | C352224
81 |  | R10 | RES_0805_M | C352224
82 |  | R11 | RES_0805_M | C352224
83 |  | R12 | RES_0805_M | C352224
84 |  | R13 | RES_0402_M | C31439
85 |  | R14 | RES_0402_M | C31439
86 |  | R15 | RES_0402_N | C313373
87 |  | R16 | RES_0805_N | C2828780
88 |  | R17 | RES_0805_N | C2828780
89 |  | R18 | RES_0805_N | C2828780
90 |  | R19 | RES_0805_N | C2828780
91 |  | R20 | RES_0805_N | C2828780
92 |  | R21 | RES_0805_N | C2828780
93 |  | R22 | RES_0805_N | C2828780
94 |  | R23 | RES_0402_N | C11702
95 |  | R24 | RES_0402_N | C11702
96 |  | R25 | RES_0402_N | C313373
97 |  | R26 | RES_0402_N | C313373
98 |  | R27 | RES_0402_N | C313373
99 |  | R28 | RES_0402_N | C313373
100 |  | R29 | RES_0603_M | C21189
101 |  | R30 | RES_0603_M | C21189
102 |  | R31 | RES_0805_M | C104209
103 |  | R32 | RES_0805_N | C3016791
104 |  | R33 | RES_0603_N | C861392
105 |  | R34 | RES_0805_N | C5204930
106 |  | R35 | RES_0805_N | C5204930
107 |  | R36 | RES_0805_N | C5204930
108 |  | R37 | RES_0603_M | C21189
109 |  | R40 | RES_0805_M | C17407
110 |  | R47 | RES_0805_M | C17618
111 |  | R38_1 | RES_0805_N | C5204930
112 |  | R38_2 | RES_0805_N | C5204930
113 |  | R39_1 | RES_0805_N | C5204930
114 |  | R39_2 | RES_0805_N | C5204930
115 |  | R41_1 | RES_0402_N | C11702
116 |  | R41_2 | RES_0402_N | C11702
117 |  | R42_1 | RES_0805_N | C5204930
118 |  | R42_2 | RES_0805_N | C5204930
119 |  | R43_1 | RES_0805_N | C5204930
120 |  | R43_2 | RES_0805_N | C5204930
121 |  | R44_1 | RES_0402_N | C11702
122 |  | R44_2 | RES_0402_N | C11702
123 |  | R4_1 | RES_0805_M | C352224
124 |  | R4_2 | RES_0805_M | C352224
125 |  | S1 | C720477 | C720477
126 |  | S2 | C720477 | C720477
127 |  | S3 | C720477 | C720477
128 |  | S4 | C720477 | C720477
129 | https://jlcpcb.com/partdetail/gswitch-GT_TF003_H018501/C5155563 | U1 | GT-TF003-H0185-01 | C5155563
130 | https://wmsc.lcsc.com/wmsc/upload/file/pdf/v2/lcsc/1811142111_Winbond-Elec-W25Q128JVSIQ_C97521.pdf | U2 | SOIC8P127_528X790X216L65X41N | C97521
131 | https://www.diodes.com/assets/Datasheets/AZ1117I.pdf | U3 | SOT223-4P230_700X165L95X70L | C108495
133 |  | U6 | RP2040 | C2040
134 | https://wmsc.lcsc.com/wmsc/upload/file/pdf/v2/lcsc/1811142111_Winbond-Elec-W25Q128JVSIQ_C97521.pdf | U7 | SOIC8P127_528X790X216L65X41N | C97521
135 |  | U8 | QFN89P40_1000X1000X90L40X20T674M | C2879851
136 | https://jlcpcb.com/partdetail/AnalogDevices-ADP323ACPZR7/C143893 | U10 | QFN17P50_300X300X80L40X24T160N | C143893
137 |  | U11 | RYQ0021A | C5942077
138 | https://www.lcsc.com/datasheet/lcsc_datasheet_2202032030_STMicroelectronics-STUSB1600AQTR_C2156023.pdf | U14_1 | QFN25P50_400X400X100L40X24T270X267M | C2156023
139 | https://www.lcsc.com/datasheet/lcsc_datasheet_2202032030_STMicroelectronics-STUSB1600AQTR_C2156023.pdf | U14_2 | QFN25P50_400X400X100L40X24T270X267M | C2156023
140 | https://datasheet.lcsc.com/lcsc/1810170913_TXC-Corp-7M12000039_C90900.pdf | Y1 | 7M12000039 | C90900
141 | file:///C:/Users/devin/Downloads/X322524MMB4SI.pdf | Y2 | X322524MMB4SI | C70583

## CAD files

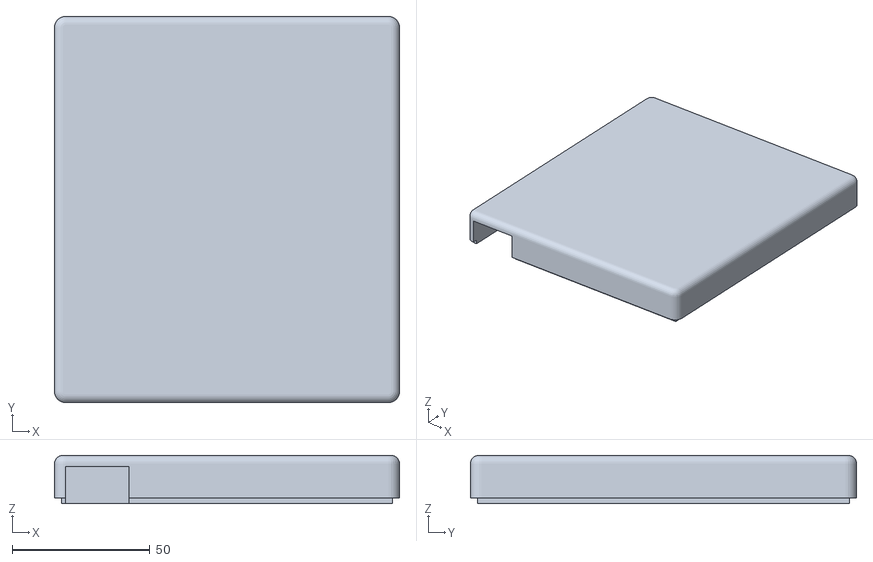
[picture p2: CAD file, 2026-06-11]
Hardware/Enclosure/SimpleSBC_EnclosureTop.stl
125.1 x 140.0 x 17.5

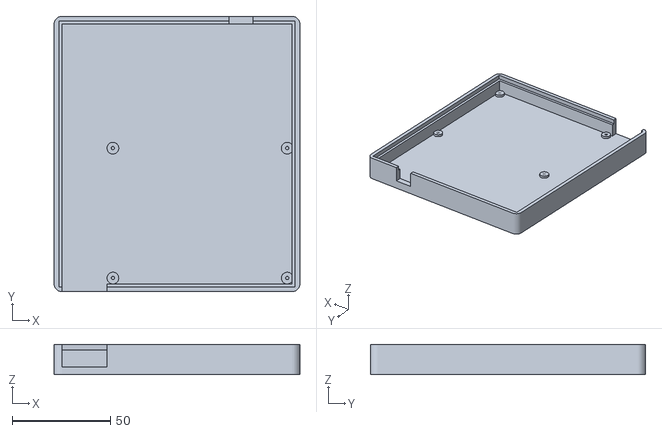
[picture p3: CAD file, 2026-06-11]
Hardware/Enclosure/SimpleSBC_EnclosureBottom.stl
125.1 x 140.0 x 15.5

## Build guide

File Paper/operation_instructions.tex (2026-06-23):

\section{Operation instructions}

The SimpleSBC platform is intended to provide a low-cost embedded Linux 
development environment for research, education, and custom instrumentation 
applications. Once assembled and programmed, the board may be operated either 
as a standalone Linux system or as the processing component of a larger 
experimental platform through the use of the expansion and peripheral 
interfaces.

\subsection{Preparing the system}

Prior to operation, verify that the board has been assembled correctly 
according to the instructions provided in the Build Instructions section. 
Confirm that a valid Linux image has been written to a microSD card using 
the Buildroot configuration supplied in the repository.

Insert the microSD card into the microSD socket and ensure that any required 
peripherals, such as displays, USB devices, serial connections, or daughter 
boards, are connected before power is applied.

\begin{figure}[h]
\centering

\caption{Overview of the assembled SimpleSBC platform showing major connectors and interfaces.}
\label{fig:board_overview}
\end{figure}

Figure \ref{fig:board_overview} should identify the microSD connector, USB-C power input, 
serial interface, user buttons, and any expansion connectors available on the board.

\subsection{Powering the board}

Connect a suitable USB power source to the USB-C connector. 
During development, it is recommended to use a current-limited bench supply or 
a USB power meter to monitor power consumption.

After power is applied, the board will begin the boot sequence automatically. 

Typical boot times are less than one minute depending on the software image and attached peripherals.
If a serial terminal is connected through the RP2040 USB-to-UART bridge, 
Linux boot messages should appear shortly after power is applied. 
Successful completion of the boot sequence is indicated by the appearance of a 
login prompt or application-specific startup messages.

\subsection{Serial console access}

During development and debugging, interaction with the system is typically 
performed through the serial console.

\begin{enumerate}
\item Connect the USB cable to the host computer.
\item Identify the serial device created by the RP2040 USB-to-UART bridge.
\item Open a terminal emulator such as PuTTY, Tera Term, minicom, screen, or picocom.
\item Configure the serial connection according to the settings specified by the software image.
\item Reset or power cycle the board if boot messages are not visible.
\end{enumerate}

The serial console provides access to Linux boot messages, diagnostic output, 
and command-line administration of the system.

\subsection{Running software}

After the system has booted successfully, user applications may be executed 
directly from the Linux command line or configured to launch automatically 
during startup.

The Buildroot image included with this work contains demonstration scripts 
and example applications that may be used to validate correct operation of 
the processor, storage system, display interface, and software environment. 
Researchers may replace these applications with custom software appropriate 
to their own experimental requirements.

The board was intentionally designed to support customization. Additional 
peripherals may be connected through the available expansion interfaces and 
controlled through Linux device drivers, user-space applications, or custom 
kernel modifications.

\subsection{Using custom daughter boards}

A significant portion of the PCB area is reserved for daughter-board integration. 
Researchers wishing to adapt the platform for specific experiments may install 
custom hardware in this area and interface with the Linux system through GPIO, 
UART, SPI, I\textsuperscript{2}C, PWM, or other available interfaces.

When integrating custom hardware:

\begin{enumerate}
\item Verify voltage compatibility with the board.
\item Confirm pin assignments using the schematic and device tree files.
\item Test new peripherals individually before integrating them into larger systems.
\item Update the Linux device tree if additional hardware resources are required.
\end{enumerate}

\subsection{Shutdown procedure}

To prevent filesystem corruption, the operating system should be shut down 
gracefully before removing power.

From the Linux command line:

\begin{verbatim}
shutdown -h now
\end{verbatim}

or

\begin{verbatim}
poweroff
\end{verbatim}

Wait until all filesystem activity has stopped before disconnecting power 
or removing the microSD card.

\subsection{Troubleshooting}

If the board does not boot:

\begin{enumerate}
\item Verify that the microSD card contains a valid software image.
\item Confirm that the power supply is capable of providing sufficient current.
\item Check for visible assembly defects or damaged components.
\item Monitor the serial console for boot messages.
\item Verify that the correct device tree and Buildroot configuration were 
used during image generation.
\end{enumerate}

If the display or peripheral hardware does not function correctly:

\begin{enumerate}
\item Verify connector orientation and cable installation.
\item Confirm that the required kernel patches and device tree configuration 
are present.
\item Check Linux system logs for driver initialization messages.
\item Verify peripheral functionality independently where possible.
\end{enumerate}

\subsection{Safety considerations}

The platform operates at low voltages and is intended for laboratory, 
educational, and research use. Nevertheless, users should avoid modifying 
the hardware while power is applied and should verify that all external 
peripherals operate within the supported voltage ranges.

Improper wiring of expansion hardware may damage the processor, peripheral 
devices, or power-management circuitry. During initial development, current 
limiting is recommended whenever new hardware is connected.

The board should not be exposed to moisture, conductive debris, or excessive 
mechanical stress. If any component becomes unusually hot during operation, 
disconnect power immediately and investigate the cause before further use.

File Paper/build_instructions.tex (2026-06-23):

\section{Build instructions}

The complete hardware design files are provided in the project repository under 
the \texttt{Hardware} directory. The board can be reproduced using the editable 
DipTrace design file, the exported Gerber archive, the bill of materials, and 
the pick-and-place file described in the Design files summary and Bill of 
materials summary.

\subsection{PCB fabrication and assembly}

The PCB was designed to be fabricated and assembled through a low-cost 
PCB manufacturing service such as JLCPCB. To reproduce the board, upload 
\texttt{Hardware/SimpleSBC_gerber.zip} to the PCB manufacturer and use the 
fabrication settings specified by the manufacturer for the submitted Gerber 
files. The component placement and sourcing information are provided in 
\texttt{Hardware/sbcPNP.csv} and \texttt{Hardware/sbcBOM.csv}. 
The reference designators in these files correspond directly to the 
designators in \texttt{Hardware/SimpleSBC.dip}.

Before ordering assembled boards, the bill of materials should be checked 
against current part availability. If any component is unavailable, the 
replacement part should be verified for footprint compatibility, electrical 
compatibility, and assembly compatibility. Particular care should be taken 
when substituting the Allwinner F1C200s processor, RP2040 microcontroller, 
SPI flash memories, USB-C controllers, voltage regulators, MOSFETs, and 
crystal oscillators, since these parts may affect boot, power sequencing, 
USB operation, or Linux compatibility.

\subsection{Design review before manufacture}

Prior to fabrication, open \texttt{Hardware/SimpleSBC.dip} in DipTrace and 
inspect the schematic and PCB layout. Confirm that the power rails, USB-C 
connectors, microSD interface, SPI flash, display interface, UART bridge, 
and user-accessible connectors match the intended revision of the hardware. 
The exported manufacturing files should be regenerated if any schematic or 
layout changes are made.

The design uses the Allwinner F1C200s as the primary Linux-capable processor. 
This device was selected because it provides a low-cost embedded Linux 
platform suitable for simple research instruments while avoiding the cost 
and size of a Raspberry Pi-class single-board computer. An RP2040 is 
included as a USB-to-UART bridge to simplify programming, debugging, and 
board bring-up. This choice reduces the need for external serial adapters 
during development and makes the board easier to reproduce in teaching or 
laboratory settings.

\subsection{Board bring-up}

After receiving the assembled PCB, visually inspect the board under 
magnification before applying power. Check for obvious solder bridges, 
missing components, incorrectly oriented components, or mechanical damage. 
Special attention should be given to fine-pitch ICs, USB-C connectors, the 
microSD socket, crystal oscillators, and power-management components.

Before inserting a microSD card or connecting the board to a host computer, 
check the resistance between each major power rail and ground. A near-short 
may indicate an assembly fault and should be investigated before power is 
applied. If a current-limited bench supply is available, power the board 
initially with a conservative current limit and monitor the input current.

Once the board passes visual and electrical inspection, connect the board 
over USB and verify that the RP2040 USB-to-UART bridge enumerates 
correctly on the host computer. The firmware for this bridge is 
provided in \texttt{Software/pico-uart-bridge}. If the bridge firmware 
must be rebuilt, use the files in that directory together with the 
Raspberry Pi Pico SDK as described in the included README file.

\subsection{Linux image preparation}

The embedded Linux image is built using the Buildroot external tree 
located in \texttt{Software/simple_sbc}. The primary board configuration 
is provided by \texttt{Software/simple_sbc/configs/f1c200s_simple_sbc_defconfig}. 
The board-specific device tree files are located in 
\texttt{Software/simple_sbc/board/simple_sbc/allwinner}. These files define the 
hardware interfaces used by the Linux kernel, including the processor configuration 
and board-level peripherals.

To build the image, configure Buildroot using the provided defconfig, 
then compile the image using the standard Buildroot workflow. 
The resulting image can be written to a microSD card. After writing the image, 
insert the microSD card into the board and apply power. Boot messages should 
be visible through the UART bridge.

\subsection{Software and display configuration}

The Buildroot tree includes board-specific files for image generation, 
boot configuration, root filesystem overlays, and Linux kernel patches. 
The patch located at \texttt{Software/simple_sbc/board/simple_sbc/patches/linux/6.14.1/0001-st7789v-support-dc-gpio-8bit-spi.patch} 
provides support for the ST7789V display interface used by the board. 
The root filesystem overlay includes startup scripts and demonstration files 
used to validate the hardware after boot.

After the board boots, confirm that the serial console is available, the microSD 
root filesystem is mounted, and the expected display or peripheral interfaces are 
detected. The included example files in the overlay directory may be used for simple 
functional testing.

\subsection{Enclosure fabrication}

The enclosure files are provided as \texttt{Hardware/Enclosure/SimpleSBC_EnclosureTop.stl} 
and \texttt{Hardware/Enclosure/SimpleSBC_EnclosureBottom.stl}. 
These parts may be fabricated using a standard 3D printer or an external printing 
service. After printing, place the assembled PCB in the bottom enclosure piece and 
verify that all connectors, buttons, and openings align before attaching the top piece.

If the design is modified, the enclosure should be checked against the updated board 
outline and connector locations. Minor dimensional adjustments may be required depending 
on the 3D printing process and material used.

\subsection{Safety considerations}

The board is intended for low-voltage embedded electronics development. 
However, the assembled PCB should still be inspected carefully before power is applied. 
Do not power the board if there are visible solder bridges, damaged components, 
or signs of overheating. During initial bring-up, use a current-limited supply where possible.

The board should not be connected directly to mains voltage. 
Any external power supply used with the board should be current-limited and appropriately rated. 
Components such as voltage regulators, MOSFETs, 
and USB-C power circuitry may become hot if incorrectly assembled, overloaded, or shorted. 
Disconnect power immediately if excessive current draw, heat, smoke, 
or unexpected behaviour is observed.

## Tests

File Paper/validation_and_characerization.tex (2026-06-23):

\section{Validation and characterization}

To validate the operation of the SimpleSBC platform, 
the board was configured as a standalone web server hosting a static website. 
This use case was selected because it exercises multiple subsystems simultaneously, 
including Linux boot, microSD storage, networking, memory management, and 
long-duration operation. The demonstration also reflects a realistic deployment 
scenario for educational, laboratory, and embedded monitoring applications.

\subsection{Website hosting demonstration}

A Linux image was generated using the Buildroot configuration described 
previously and written to a microSD card. Following boot, a lightweight 
web server was installed and configured to serve a static website over 
the board's network interface.

Figure \ref{fig:webserver_demo} shows the test setup used for validation. 
The SimpleSBC was connected to a local area network and accessed from a 
separate client computer using a standard web browser.

\begin{figure}[h]
\centering

\caption{Validation setup showing the SimpleSBC hosting a website accessible from a remote client.}
\label{fig:webserver_demo}
\end{figure}

The website remained accessible throughout testing and demonstrated 
successful operation of the processor, memory subsystem, storage interface, 
operating system, and network stack. This validation confirms that the 
hardware can support practical Linux-based workloads and may serve as the 
foundation for more specialized scientific applications.

\subsection{Performance characterization}

The objective of this work is not to maximize computational performance 
but rather to provide a low-cost and highly customizable Linux-capable 
embedded platform. Therefore, characterization focused on validating 
correct operation rather than comparing performance against higher-end 
commercial single-board computers.

System functionality was evaluated using:

\begin{enumerate}
\item Successful Linux boot from microSD storage.
\item Reliable operation of the serial console.
\item Network connectivity.
\item Successful hosting of a static website.
\item Continuous operation without unexpected system crashes during testing.
\end{enumerate}

Future users may further characterize the platform for application-specific 
metrics such as network throughput, processor utilization, power consumption, 
storage performance, or peripheral response times.

\subsection{Capabilities and limitations}

The capabilities and limitations observed during validation are summarized below.

\begin{itemize}
\item Supports a complete Linux operating system generated using Buildroot.

```
\item Can host lightweight network services such as web servers, data loggers, 
remote monitoring systems, and laboratory control interfaces.

\item Provides a low-cost alternative to larger commercial single-board computers 
for embedded applications.

\item Supports customization through both hardware modifications and software 
configuration.

\item Includes accessible design files allowing adaptation to application-specific 
requirements.

\item Can be fabricated using commercially available PCB assembly services without 
requiring specialized manufacturing equipment.

\item Offers substantially lower computational performance than modern Raspberry 
Pi platforms.

\item Limited memory and processor resources make the platform unsuitable for 
computationally intensive workloads such as machine learning inference, 
computer vision, or multimedia processing.

\item Storage performance is constrained by the microSD interface.

\item Peripheral support is dependent on Linux kernel support and available 
device drivers.
```

\end{itemize}

The validation results demonstrate that the platform successfully fulfills its 
intended role as a compact and customizable Linux-capable single-board computer 
suitable for educational, research, and embedded instrumentation applications.

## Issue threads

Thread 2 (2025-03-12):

Board Changes for Revision

devinatkin, 2025-03-12:
- Fix the SD Card (Done, Verify before ordering)
- Fix USB power delivery (Swap out the singular MAX40200 power supply ideal diodes, replace them with a parallel pair which will be switched by STUSB1600AQTR for direction control)

Closed 2025-05-01.

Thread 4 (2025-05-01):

Board Changes for Follow Up Revision

devinatkin, 2025-05-01:
Add output amplifier to audio output to prevent crash issue
Replace STUSB1600 with STUSB1602
Add Silk Screen to Indicate Daughter board pinout

Add power meter
---

Create a daughter board with ESP32 based WiFi, RA8875 board header, SPO2 Monitor Header, BNO055 I2C OLED header, Light Sensor or header

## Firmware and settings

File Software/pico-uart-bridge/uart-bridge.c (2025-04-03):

// SPDX-License-Identifier: MIT
/*
 * Copyright 2021 Álvaro Fernández Rojas <noltari@gmail.com>
 */

#include <hardware/irq.h>
#include <hardware/structs/sio.h>
#include <hardware/uart.h>
#include <pico/multicore.h>
#include <pico/stdlib.h>
#include <string.h>
#include <tusb.h>

#if !defined(MIN)
#define MIN(a, b) ((a > b) ? b : a)
#endif /* MIN */

#define LED_PIN 21

#define BUFFER_SIZE 2560

#define DEF_BIT_RATE 115200
#define DEF_STOP_BITS 1
#define DEF_PARITY 0
#define DEF_DATA_BITS 8

typedef struct {
	uart_inst_t *const inst;
	uint irq;
	void *irq_fn;
	uint8_t tx_pin;
	uint8_t rx_pin;
} uart_id_t;

typedef struct {
	cdc_line_coding_t usb_lc;
	cdc_line_coding_t uart_lc;
	mutex_t lc_mtx;
	uint8_t uart_buffer[BUFFER_SIZE];
	uint32_t uart_pos;
	mutex_t uart_mtx;
	uint8_t usb_buffer[BUFFER_SIZE];
	uint32_t usb_pos;
	mutex_t usb_mtx;
} uart_data_t;

void uart0_irq_fn(void);
// void uart1_irq_fn(void);

const uart_id_t UART_ID[CFG_TUD_CDC] = {
	{
		.inst = uart0,
		.irq = UART0_IRQ,
		.irq_fn = &uart0_irq_fn,
		.tx_pin = 16,
		.rx_pin = 17,
	}
	// , {
	// 	.inst = uart1,
	// 	.irq = UART1_IRQ,
	// 	.irq_fn = &uart1_irq_fn,
	// 	.tx_pin = 4,
	// 	.rx_pin = 5,
	// }
};

uart_data_t UART_DATA[CFG_TUD_CDC];

static inline uint databits_usb2uart(uint8_t data_bits)
{
	switch (data_bits) {
		case 5:
			return 5;
		case 6:
			return 6;
		case 7:
			return 7;
		default:
			return 8;
	}
}

static inline uart_parity_t parity_usb2uart(uint8_t usb_parity)
{
	switch (usb_parity) {
		case 1:
			return UART_PARITY_ODD;
		case 2:
			return UART_PARITY_EVEN;
		default:
			return UART_PARITY_NONE;
	}
}

static inline uint stopbits_usb2uart(uint8_t stop_bits)
{
	switch (stop_bits) {
		case 2:
			return 2;
		default:
			return 1;
	}
}

void update_uart_cfg(uint8_t itf)
{
	const uart_id_t *ui = &UART_ID[itf];
	uart_data_t *ud = &UART_DATA[itf];

	mutex_enter_blocking(&ud->lc_mtx);

	if (ud->usb_lc.bit_rate != ud->uart_lc.bit_rate) {
		uart_set_baudrate(ui->inst, ud->usb_lc.bit_rate);
		ud->uart_lc.bit_rate = ud->usb_lc.bit_rate;
	}

	if ((ud->usb_lc.stop_bits != ud->uart_lc.stop_bits) ||
	    (ud->usb_lc.parity != ud->uart_lc.parity) ||
	    (ud->usb_lc.data_bits != ud->uart_lc.data_bits)) {
		uart_set_format(ui->inst,
				databits_usb2uart(ud->usb_lc.data_bits),
				stopbits_usb2uart(ud->usb_lc.stop_bits),
				parity_usb2uart(ud->usb_lc.parity));
		ud->uart_lc.data_bits = ud->usb_lc.data_bits;
		ud->uart_lc.parity = ud->usb_lc.parity;
		ud->uart_lc.stop_bits = ud->usb_lc.stop_bits;
	}

	mutex_exit(&ud->lc_mtx);
}

void usb_read_bytes(uint8_t itf)
{
	uart_data_t *ud = &UART_DATA[itf];
	uint32_t len = tud_cdc_n_available(itf);

	if (len &&
	    mutex_try_enter(&ud->usb_mtx, NULL)) {
		len = MIN(len, BUFFER_SIZE - ud->usb_pos);
		if (len) {
			uint32_t count;

			count = tud_cdc_n_read(itf, &ud->usb_buffer[ud->usb_pos], len);
			ud->usb_pos += count;
		}

		mutex_exit(&ud->usb_mtx);
	}
}

void usb_write_bytes(uint8_t itf)
{
	uart_data_t *ud = &UART_DATA[itf];

	if (ud->uart_pos &&
	    mutex_try_enter(&ud->uart_mtx, NULL)) {
		uint32_t count;

		count = tud_cdc_n_write(itf, ud->uart_buffer, ud->uart_pos);
		if (count < ud->uart_pos)
			memmove(ud->uart_buffer, &ud->uart_buffer[count],
			       ud->uart_pos - count);
		ud->uart_pos -= count;

		mutex_exit(&ud->uart_mtx);

		if (count)
			tud_cdc_n_write_flush(itf);
	}
}

void usb_cdc_process(uint8_t itf)
{
	uart_data_t *ud = &UART_DATA[itf];

	mutex_enter_blocking(&ud->lc_mtx);
	tud_cdc_n_get_line_coding(itf, &ud->usb_lc);
	mutex_exit(&ud->lc_mtx);

	usb_read_bytes(itf);
	usb_write_bytes(itf);
}

void core1_entry(void)
{
	tusb_init();

	while (1) {
		int itf;
		int con = 0;

		tud_task();

		for (itf = 0; itf < CFG_TUD_CDC; itf++) {
			if (tud_cdc_n_connected(itf)) {
				con = 1;
				usb_cdc_process(itf);
			}
		}

		gpio_put(LED_PIN, con);
	}
}

static inline void uart_read_bytes(uint8_t itf)
{
	uart_data_t *ud = &UART_DATA[itf];
	const uart_id_t *ui = &UART_ID[itf];

	if (uart_is_readable(ui->inst)) {
		mutex_enter_blocking(&ud->uart_mtx);

		while (uart_is_readable(ui->inst) &&
		       (ud->uart_pos < BUFFER_SIZE)) {
			ud->uart_buffer[ud->uart_pos] = uart_getc(ui->inst);
			ud->uart_pos++;
		}

		mutex_exit(&ud->uart_mtx);
	}
}

void uart0_irq_fn(void)
{
	uart_read_bytes(0);
}

// void uart1_irq_fn(void)
// {
// 	uart_read_bytes(1);
// }

void uart_write_bytes(uint8_t itf)
{
	uart_data_t *ud = &UART_DATA[itf];

	if (ud->usb_pos &&
	    mutex_try_enter(&ud->usb_mtx, NULL)) {
		const uart_id_t *ui = &UART_ID[itf];
		uint32_t count = 0;

		while (uart_is_writable(ui->inst) &&
		       count < ud->usb_pos) {
			uart_putc_raw(ui->inst, ud->usb_buffer[count]);
			count++;
		}

		if (count < ud->usb_pos)
			memmove(ud->usb_buffer, &ud->usb_buffer[count],
			       ud->usb_pos - count);
		ud->usb_pos -= count;

		mutex_exit(&ud->usb_mtx);
	}
}

void init_uart_data(uint8_t itf)
{
	const uart_id_t *ui = &UART_ID[itf];
	uart_data_t *ud = &UART_DATA[itf];

	/* Pinmux */
	gpio_set_function(ui->tx_pin, GPIO_FUNC_UART);
	gpio_set_function(ui->rx_pin, GPIO_FUNC_UART);

	/* USB CDC LC */
	ud->usb_lc.bit_rate = DEF_BIT_RATE;
	ud->usb_lc.data_bits = DEF_DATA_BITS;
	ud->usb_lc.parity = DEF_PARITY;
	ud->usb_lc.stop_bits = DEF_STOP_BITS;

	/* UART LC */
	ud->uart_lc.bit_rate = DEF_BIT_RATE;
	ud->uart_lc.data_bits = DEF_DATA_BITS;
	ud->uart_lc.parity = DEF_PARITY;
	ud->uart_lc.stop_bits = DEF_STOP_BITS;

	/* Buffer */
	ud->uart_pos = 0;
	ud->usb_pos = 0;

	/* Mutex */
	mutex_init(&ud->lc_mtx);
	mutex_init(&ud->uart_mtx);
	mutex_init(&ud->usb_mtx);

	/* UART start */
	uart_init(ui->inst, ud->usb_lc.bit_rate);
	uart_set_hw_flow(ui->inst, false, false);
	uart_set_format(ui->inst, databits_usb2uart(ud->usb_lc.data_bits),
			stopbits_usb2uart(ud->usb_lc.stop_bits),
			parity_usb2uart(ud->usb_lc.parity));
	uart_set_fifo_enabled(ui->inst, false);

	/* UART RX Interrupt */
	irq_set_exclusive_handler(ui->irq, ui->irq_fn);
	irq_set_enabled(ui->irq, true);
	uart_set_irq_enables(ui->inst, true, false);
}

int main(void)
{
	int itf;

	usbd_serial_init();

	for (itf = 0; itf < CFG_TUD_CDC; itf++)
		init_uart_data(itf);

	gpio_init(LED_PIN);
	gpio_set_dir(LED_PIN, GPIO_OUT);

	multicore_launch_core1(core1_entry);

	while (1) {
		for (itf = 0; itf < CFG_TUD_CDC; itf++) {
			update_uart_cfg(itf);
			uart_write_bytes(itf);
		}
	}

	return 0;
}

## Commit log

2024-08-28 Board Organization and Readme
    [BOM.csv, PNP.csv]
2024-08-28 Updated Board Schematic - Integrate RP2040, Consolidate Headers, Add SD Card
2024-08-28 functional design cloned from public repo
    [genimage.cfg]
2024-08-28 Adds Lua and Support for Both on board LEDs
2024-08-28 Started Board Layout Update
2024-08-30 Updated Board Layout
2024-08-30 Updated BOM and PNP files
    [BOM.csv, PNP.csv]
2024-08-30 Fixing BOM 1
    [BOM.csv]
2024-10-02 Updated SIngle Board Computer Design
    [SimpleSBC_BillOfMaterials.csv, SimpleSBC_PickAndPlace.csv]
2024-10-02 Board Ready to Order
    [SimpleSBC_BillOfMaterials.csv]
2024-10-02 Fix 2x20 2.54mm Header Part (Changed to DNP)
    [SimpleSBC_BillOfMaterials.csv]
2024-10-02 Correct C5 to 0402 Component
    [SimpleSBC_BillOfMaterials.csv]
2024-10-09 Update Parts for Actual Order
    [SimpleSBC_BillOfMaterials.csv]
2024-10-11 Updated PCB Design
2024-10-17 Update Board to fix error
2024-10-31 Change Led Pin from PE11 to PD1
2024-10-31 Change Led Pin from PE12 to PD2
2024-10-31 Add Led Pin PD3
2024-10-31 Add Led Pin PD21
2024-12-11 Rename f1c100-business-card directory to simple_sbc
    [genimage.cfg]
2024-12-12 Squashed 'Software/pico-uart-bridge/' content from commit 9d0df32
    git-subtree-dir: Software/pico-uart-bridge
    git-subtree-split: 9d0df3277dcbbbcc9dd5e847205407560f512194
2024-12-12 Add Subtree pico uart bridge
2024-12-12 Update Genimage size
    [genimage.cfg]
2024-12-12 Corrent Number of Pebs
    [genimage.cfg]
2024-12-12 Change the board name
    [genimage.cfg]
2024-12-13 fix build commands
    [genimage.cfg]
2025-03-04 added increased zimage
    [genimage.cfg]
2025-03-05 increasing rootfs image size
    [genimage.cfg]
2025-03-13 added not working version of spi
2025-03-20 Board Updates
    [SimpleSBC_BillOfMaterials.csv, SimpleSBC_PickAndPlace.csv, sbcBOM.csv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]
2025-04-03 Fix UART pico uart bridge CI code
2025-04-03 update led pin
2025-04-03 Update to only pass forward the default console uart 0
2025-04-03 update led 3 pin
2025-04-08 added sd card version of kernel
    [genimage.cfg]
2025-04-10 added new new boot partition
    [genimage.cfg]
2025-04-11 added 6.14.1 version of kernel with drm and dma
    [genimage.cfg]
2026-06-11 Add Initial Enclosure for Simple SBC (Running Webserver)
    [SimpleSBC_EnclosureBottom.stl, SimpleSBC_EnclosureTop.stl]
2026-06-23 AI Bill Of Materials (REPLACE)
